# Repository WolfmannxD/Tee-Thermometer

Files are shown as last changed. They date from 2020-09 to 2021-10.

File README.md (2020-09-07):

# Tee-Thermometer

This is a small arduino project which helps to track the temperature of a hot drink. It is based on an Arduino Nano and a DS1020 digital temperature sensor. This sensor can be connected directly to the Arduino without any additional circuitry. As output, I use a 128x64 OLED Display with I2C interface. 
The temperature is logged and used to extrapolate the time when the desired temperature is reached. This is accomplished by doing a linear regression on the logarithm of the temperatures, to simplify the computation. For more information on the calculations see Tee-Thermometer.pdf. 

The main function of this device is the calculation and display of the remaining time until the tea (or other hot drink) has cooled enough to be drinkable. It also shows the remaining time until the drink is too cold. The temperature values may vary from person to person and must be changed in the sketch directly.

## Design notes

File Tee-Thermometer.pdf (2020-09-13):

## Tee-Thermometer

Zielsetzung:

Jeder kennt das Problem: Direkt nach dem Aufbrühen ist der Tee zu heiß zum Trinken, also lässt man ihn auskühlen. Dabei verliert man ihn jedoch schnell aus den Augen, und denkt erst an ihn, wenn er bereits zu kalt ist. Um diesem Problem entgegenzuwirken habe ich mir folgendes Hilfsmittel ausgedacht: Ein Gerät, welches die Temperatur des Tees misst, und die verbleibende Wartezeit berechnet bis eine gewünschte Temperatur erreicht ist. So hat man die verbleibende Zeit immer im Blick, und muss nicht immer die Temperatur erfühlen. Außerdem lässt sich leicht ein Alarm implementieren, falls gewünscht.

Theorie / Funktionsweise:

Es gibt verschiedene Herangehensweisen, um dieses Problem zu lösen. Am einfachsten ist es, den Temperaturverlauf eines typischen Tees zu messen, und daraus die benötigte Zeit zum Abkühlen abzuleiten. Bei der gleichen Anfangstemperatur, Umgebungstemperatur und Tasse dauert es immer gleich lang, bis der Tee die gewünschte Temperatur erreicht hat. Dies könnte man als open-loop Vorgehensweise bezeichnen.

Eine aufwändigere Methode ist es, die Temperatur in regelmäßigen Abständen zu messen, und daraus den Zeitpunkt für das Erreichen einer gewünschten Temperatur zu extrapolieren. Damit ist die Vorhersage nicht von eingegebenen Parametern wie der Umgebungstemperatur oder der Tasse abhängig. Außerdem wird dadurch die veränderte Abkühlzeit durch eine Verringerung der Flüssigkeitsmenge und dem Durchmischen der Flüssigkeit berücksichtigt.

Implementierung:

Da komplexe Berechnungen vorgenommen werden müssen, ist die Verwendung eines Microcontrollers unerlässlich. Hier wurde der Arduino Nano verwendet. Im Nachhinein betrachtet, wäre ein leistungsfähigerer Chip besser geeignet, aber für die Funktion reicht der Nano aus. Als Temperatursensor wurde der DS18B20 verwendet. Dies ist ein digitaler Temperatursensor, welcher mit nur einem Pin verbunden werden muss, und die Temperatur bereits digital übermittelt. Dadurch sind keine weiteren Bauteile notwendig, um die Temperatur auszulesen. Ein weiterer Vorteil ist die hohe Genauigkeit der Temperaturmessung, welche mit +- 0.2 °C angegeben wird.

Als Berechnungsgrundlage für das Auskühlen einer Flüssigkeit gilt eine Exponentialfunktion mit Offset.

T(t) = T0 e

−k t + TU

Wobei T0 die Anfangstemperatur, k die Abkühlrate und TU die Umgebungstemperatur darstellen. Da die Umgebungstemperatur, sowie die Anfangstemperatur nicht aus den Messwerten ersichtlich sind müssen sie als freie Parameter in der Modellfunktion berücksichtigt werden.

Um einen Fit der Temperaturmesswerte an diese Exponentialfunktion durchzuführen, wende ich einen Trick an. Vernachlässigen wir zunächst die Umgebungstemperatur. Angenommen sie ist bekannt, kann sie von den Messwerten subtrahiert werden. Dies vereinfacht die Formel. Jetzt kann man durch logarithmieren der Gleichung einen linearen Zusammenhang zwischen dem Logarithmus der Messwerte und der Abkühlkonstanten k erhalten. Hiermit ist es möglich eine lineare Regression durchzuführen, was sehr wenig Rechenaufwand im Vergleich zu einer nichtlinearen Optimierung erfordert. Da der Arduino Nano geringe Ressourcen aufweist, ist dies hier notwendig. Die Gleichung für den Temperaturverlauf kann wie folgt umgeschrieben werden:

l⏟n ( T − T U )

y

= −⏟k

a

⏟t

x

+ ln(T0 ⏟ )

b

Dies hat die Form einer linearen Gleichung. Die Parameter a und b können mittels einer linearen Regression bestimmt werden.

b =

∑(xi − x̅)yi
∑(xi − x̅)

2

a = y̅ − bx̅

Dabei sind x̅und y̅ die Mittelwerte von x und y.

Damit können die Parameter T0 und k bestimmt werden, was die Berechnung des Zeitpunkts des Erreichens der Trinktemperatur ermöglicht.

T0 = e

b

k = −a

Da die Umgebungstemperatur nicht bestimmt werden kann, muss die vorhergehende Berechnung für mehrere Werte für TU erfolgen, und daraus per brute-force Optimierung der am besten passende Wert bestimmt werden.

Fertigstellung:

Um das Gerät bequem nutzen zu können, wurde ein 64x32 OLED Display zur Anzeige der Temperatur und verbleibenden Zeit eingesetzt. Zusätzlich wird die verbleibende Zeit bis der Tee zu kalt ist angezeigt, damit man ihn nicht zu lange stehen lässt. Um einen mobilen Einsatz zu gewährleisten wurde ein Lithium-Ionen-Akku zusammen mit einem Lade- und Schutzschaltung basierend auf dem TP4056 Chip sowie ein Boost-Converter verwendet. Dies ermöglicht ein Laden des Akkus über micro USB. Anschließend habe ich ein passendes Gehäuse entworfen und mit einem 3D-Drucker hergestellt.

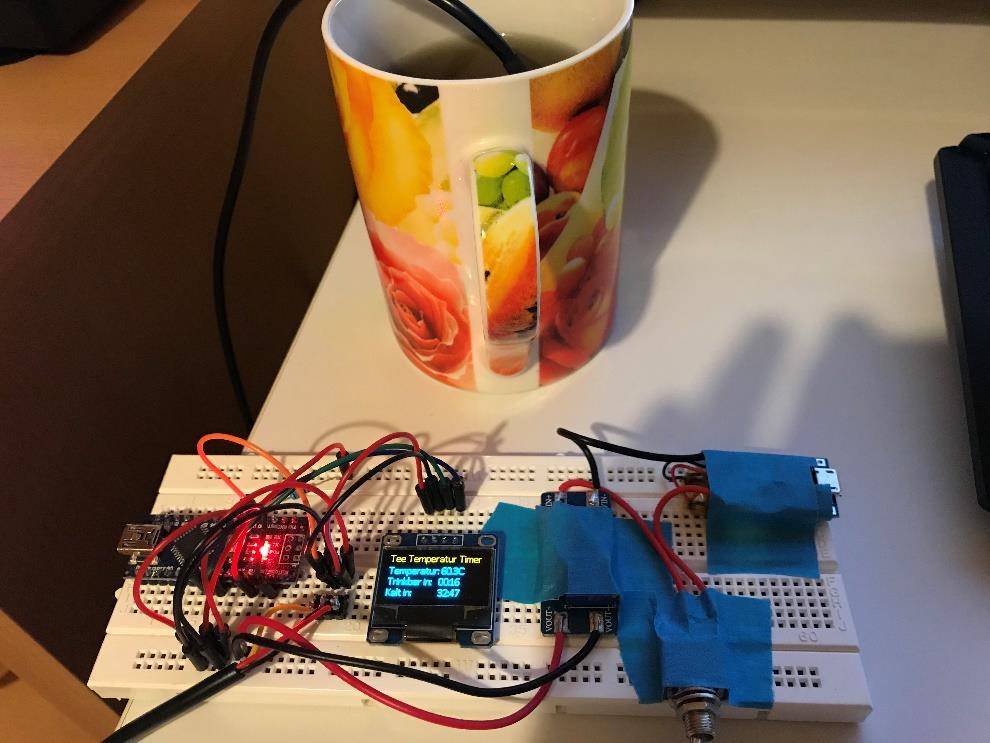
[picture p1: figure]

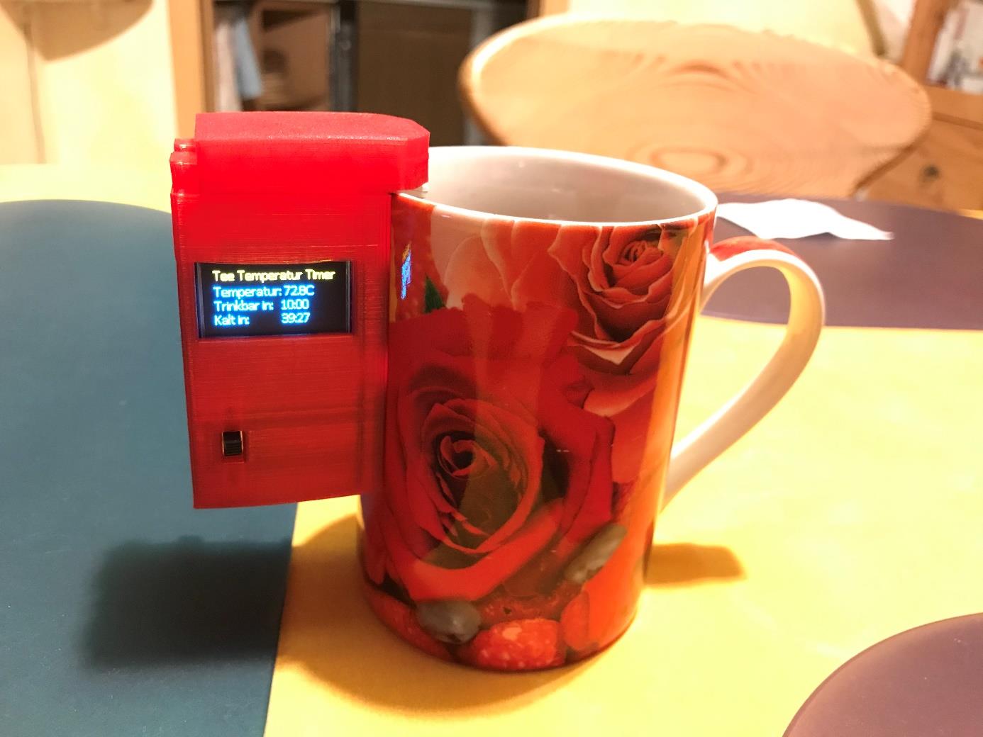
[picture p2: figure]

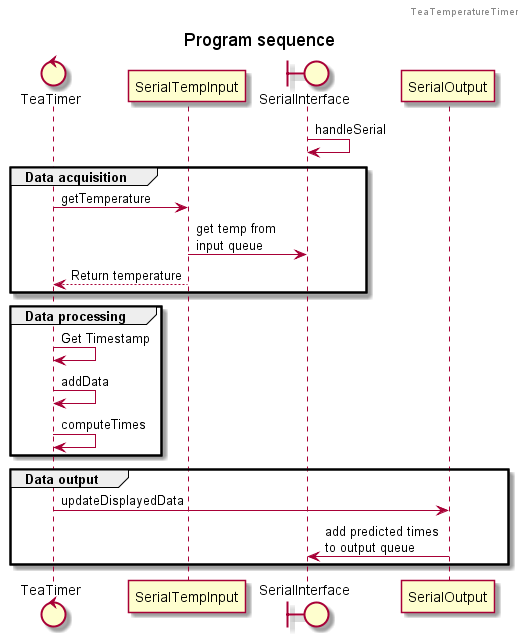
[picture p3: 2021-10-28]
Modelling/out/TeeTempearturTimer/Sequence.png

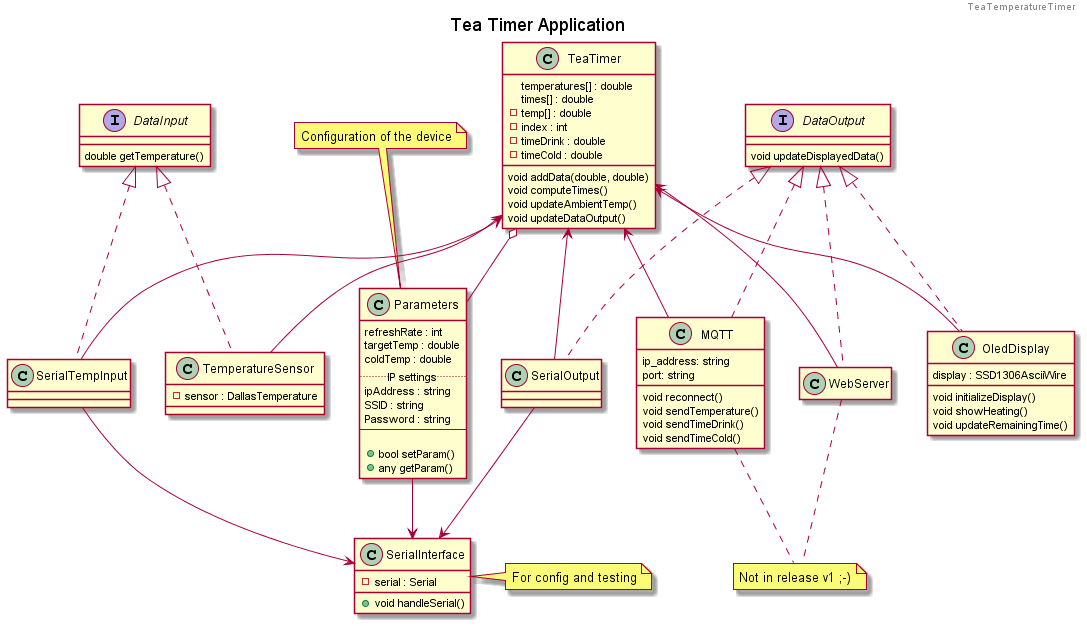
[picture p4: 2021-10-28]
Modelling/out/TeeTempearturTimer/Tea Timer Application.png

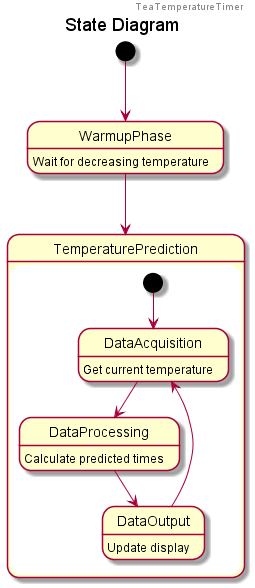
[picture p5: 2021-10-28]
Modelling/out/TeeTempearturTimer/State.png

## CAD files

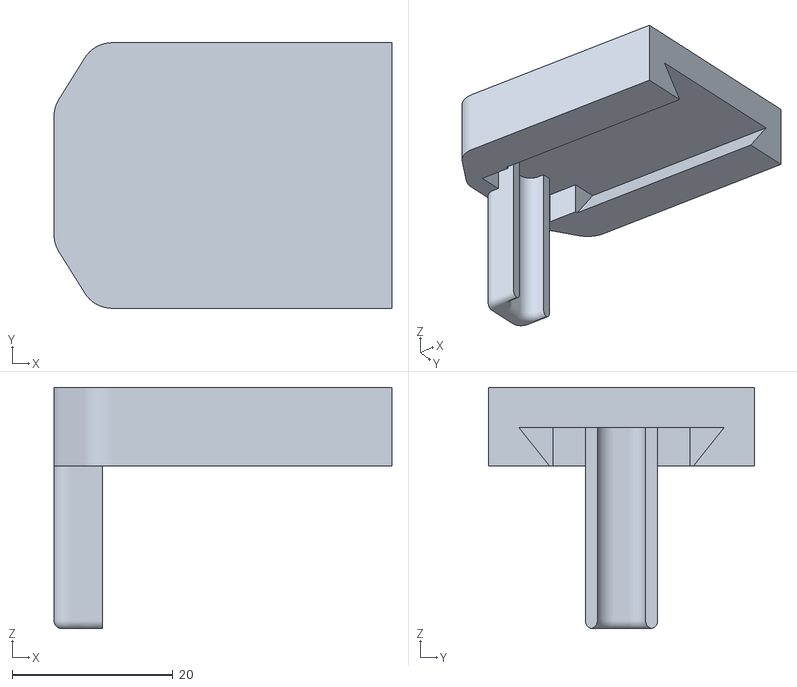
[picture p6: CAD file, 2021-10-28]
STL/Slider V4.stl
42.0 x 33.0 x 30.0

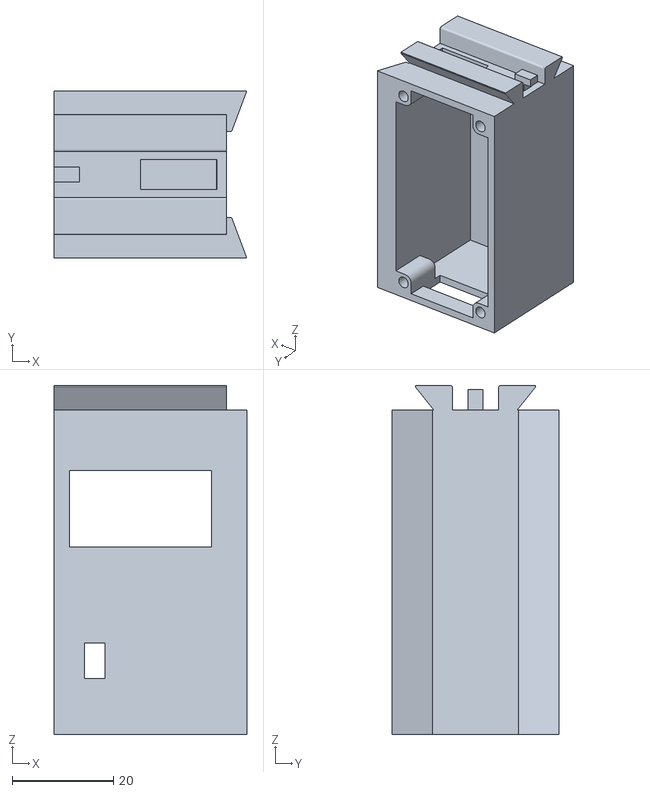
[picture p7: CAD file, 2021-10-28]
STL/Hauptteil V4.stl
38.0 x 33.0 x 68.8

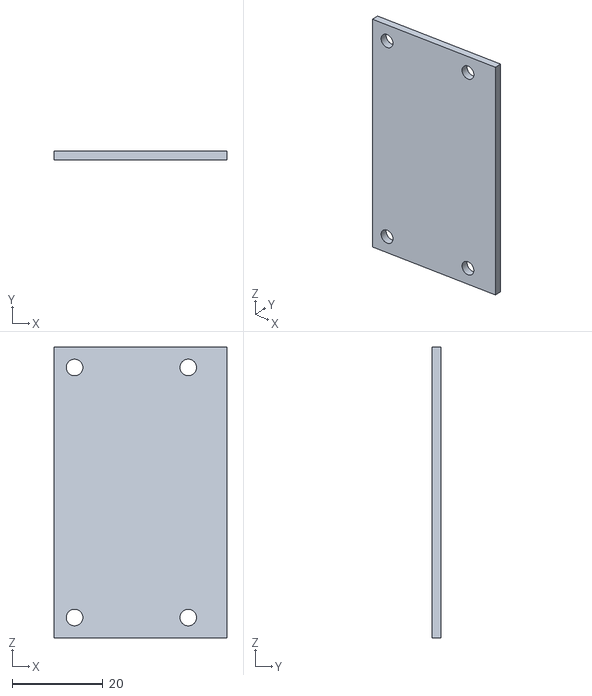
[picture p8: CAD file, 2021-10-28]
STL/Deckel V4.stl
38.0 x 2.00 x 64.0

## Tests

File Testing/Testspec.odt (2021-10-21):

Testspecification for the TeaTimer Application

# Parameter configuration

### Read parameters via serial interface

Requirement: Verify that parameters can be read via the serial interface.

Test setup: Configure the device for simulated temperature input via serial connection.

Send temperature data that puts the device out of pre-heat mode.

Check that the device is in measurement mode.

Test steps: 1. Send the string “Get Param $Param” via serial connection.

2. Wait for the answer of the device with a timeout of 200 ms.

3. Check that the answer is of the expected data type $dType.

Test parameters:

This test needs to be done for all readable parameters.

Parameter name | $Param | $dType
Refresh rate | refreshRate | Int
Target temperature | targetTemp | Double
Cold temperature | coldTemp | Double
WLAN SSID | SSID | String

### Write parameters via serial interface with valid values

Requirement: Verify that parameters can be written via the serial interface when the written value is of the correct data type and in the allowed range.

Test setup: Configure the device for simulated temperature input via serial connection.

Send temperature data that puts the device out of pre-heat mode.

Check that the device is in measurement mode.

Test steps: 1. Send the string “Set Param $Param $Value” via serial connection.

2. Wait for the answer of the device with a timeout of 200 ms.

3. Check that the answer of the device is “OK”.

4. Send the string “Get Param $Param” via serial connection.

5. Wait for the answer of the device with a timeout of 200 ms.

6. Check that the answer is $Value.

Test parameters:

This test needs to be done for all writable parameters.

Parameter name | $Param | $Value
Refresh rate | refreshRate | 5 [seconds]
Target temperature | targetTemp | 77.5 [degree Celsius]
Cold temperature | coldTemp | -1.0 [degree Celsius]
WLAN SSID | SSID | My Home Network

### Write parameters via serial interface with invalid values

Requirement: Verify that writing a parameter with an invalid value does not change the parameter. The device should not crash.

Test setup: Configure the device for simulated temperature input via serial connection. Send temperature data that puts the device out of pre-heat mode. Check that the device is in measurement mode.

Test steps: 1. Send the string “Set Param $Param $Value” via serial connection. 2. Wait for the answer of the device with a timeout of 200 ms. 3. Check that the answer of the device is “ERROR”. 4. Send the string “Get Param $Param” via serial connection. 5. Wait for the answer of the device with a timeout of 200 ms. 6. Check that the answer is not $Value.

### Write parameters and check reaction of the output

Requirement: Verify that written parameters are reloaded in the system by observing a change in the output.

Test setup: Configure the device for simulated temperature input via serial connection. Send temperature data that puts the device out of pre-heat mode. Check that the device is in measurement mode. Start sending simulated temperature data over serial connection.

Test steps: 1. Set the parameter ‘targetTemp’ to 60 °C over serial connection. 2. Wait until enough data points for time computation have been sent. 3. Get the parameter ‘timeDrink’ via serial connection as $Time_1. 4. Set the parameter ‘targetTemp’ to 40 °C over serial connection. 5. Get the parameter ‘timeDrink’ via serial connection as $Time_2. 6. Check that $Time_2 > $Time_1.

# Data processing

TBD

# Performance tests

### Test prediction accuracy with perfect data

Requirement: Verify that the extrapolated temperatures are correct within a tolerance of 5% when perfect test data is used. The time predictions shall be checked in regular intervals.

Test setup: Configure the device for simulated temperature input via serial connection.

Check that the device is in pre-heat mode.

Start sending simulated temperature data over serial connection.

Test steps: 1. Check that the device is in measurement mode when the temperature reaches 75 °C. 2. Get the parameter ‘timeDrink’ and compare it with the expected value every 5 °C until 30 °C is reached. Check that the value has a maximum deviation of 5%.

### Test prediction accuracy with data with artifacts in it

Requirement: Verify that the predicted times do not deviate more than 20% when a peak in the temperature data occurs.

### Test prediction accuracy with data with a changing slope

Requirement: Verify that the predicted time adapts in a reasonable way when the slope of the temperature curve is changing. Unrealistic results shall be rejected until the prediction has stabilized.

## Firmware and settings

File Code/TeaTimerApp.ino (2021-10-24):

#include <Arduino.h>
#include <OneWire.h>
#include <DallasTemperature.h>
#include <math.h>
#include <Wire.h>
#include "SSD1306Ascii.h"
#include "SSD1306AsciiWire.h"
#include <iostream>
#include <string>
// #include <ESP8266WiFi.h>  // macht immer noch Probleme ...
// #include <PubSubClient.h>

#include "include/TeaTimer.h"  // WTF es darf nicht im selben Verzeichnis sein???

// State of the system
bool SERIAL_ACTIVE{false};
SerialTempInput dataInput;
SerialInterface *serial;

// the setup function is run once after startup
void setup() {
    serial = new SerialInterface(); // Serial.begin etc. inside constructor
    dataInput = SerialTempInput(serial);
}

// the loop function is looped indefinitely after setup
void loop() {
    static double T;
    serial->handleSerial();
    T = dataInput.getTemperature();
    delay(2000);
    serial->write_str(String(T));
}

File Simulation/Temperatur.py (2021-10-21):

import os
import serial
import matplotlib.pyplot as plt
#import io
import time
import numpy as np
from scipy.optimize import curve_fit
import re
#import threading


def fit_func(x, a, k, c, d):
    return a*np.exp(-(x-d)*k) + c


def fit_func_ambient(x, a, k):
    return a*np.exp(-(x)*k) + T_ambient


def lin_fit(time, temperatures):
    """Use with fit_func_ambient"""
    x = time
    y = np.log(temperatures - T_ambient)
#    n = len(time)
    x_average = np.average(x)
    y_average = np.average(y)
#    b = (np.sum(x*y) - n*x_average*y_average)/(np.sum(x**2) - n*x_average**2)
    b = np.sum((x - x_average)*y)/np.sum((x - x_average)**2)
    a = y_average - b*x_average
    
    # convert
    A = np.exp(a)
    k = -b
    
    return A, k


def expofit(time, temperatures):
    xinit = 7.85, 1e-2, 20, 40
    bounds = ([0,0,0,0], [np.inf, np.inf, np.inf, np.inf])
    time = np.array(time)
    temperatures = np.array(temperatures)
    popt = curve_fit(fit_func, time, temperatures, p0=xinit, bounds=bounds)
    
    return popt


def expofit_ambient(time, temperatures):
    xinit = 7.85, 1e-2
    bounds = ([0,0], [np.inf, np.inf])
    time = np.array(time)
    temperatures = np.array(temperatures)
    popt = curve_fit(fit_func_ambient, time, temperatures, p0=xinit, bounds=bounds)
    
    return popt


def linfit(time, temperatures):
    time = np.array(time)
    temperatures = np.array(temperatures)
    popt = lin_fit(time, temperatures)
    
    return popt


def plot_data(t, T, times, data, T_trink):
    """Create the plot"""
    try:
#        print('fit')
        # popt, pcov = expofit(times, data)
#        popt2, pcov2 = expofit_ambient(times, data)
        popt3 = linfit(times, data)
        # print(popt)       
#        a, k, c, d = popt
        a, k = popt3
#        print(popt3)
#        if c < T_trink:
#            time_trink = d - np.log((T_trink - c)/a)/k
        time_trink = np.log(a/(T_trink - T_ambient))/k
        wait_time = (time_trink - times[-1])/60 # in minutes
        if wait_time < 60: # less than an hour
            if wait_time < 1:
                mesg = 'Trinkbar in {:} Sekunden'.format(int(wait_time*60))
            else:
                mesg = 'Trinkbar in {:} Minuten'.format(int(wait_time))
#            print("plot")
#            x = np.linspace(times[0], times[-1]+60, 100) # + one minute
            x = np.linspace(t[0], t[-1], 100)
            plt.clf()
            plt.ylim(30, 95)
            plt.plot(t, T, '--', color='grey')
            plt.plot(times, data, '.')
            # plt.plot(x, fit_func(x, *list(popt)), label='Normal')
#            plt.plot(x, fit_func_ambient(x, *list(popt2)), label='Ambient')
            plt.plot(x, fit_func_ambient(x, *list(popt3)), label='Linear')
            plt.plot([t[0], t[-1]], [T_trink, T_trink], '--', color='grey')
            plt.legend(loc='upper right')
            plt.title(mesg, fontsize=14)
            plt.annotate("{}".format(data[-1]), xy=(times[-1], data[-1]), xycoords='data', xytext=(5, 2), textcoords='offset points')
        plt.xlabel("t [s]")
        plt.ylabel("T [$^{\circ}$C]")
    except Exception as e:
        print(e)
    finally:
        plt.pause(0.0001)
#        plt.ion()


def temperature_logger():
    try:
        arduino = serial.Serial("Com3", timeout=15)
        # sio = io.TextIOWrapper(io.BufferedRWPair(arduino, arduino))
    except Exception as e:
        print("Please check port")
        print(e)
    print('Begin plotting')
    data = []    
    times = []
    t_zero = time.time() # Starting time
#    delta_t = 0.5 # interval in seconds
    duration = 3*60*60 # 60 minutes
    T_trink = 60 # Target temperature
    try:
        while time.time() - t_zero < duration:
#            received = arduino.readline()
#            if re.fullmatch(r"\d{2}\.\d{2}", received) is None:
#                continue
            data.append(float(arduino.readline()))
            new_time = time.time()-t_zero
            times.append(new_time)
            plt.figure(0)
            plt.ion()
            plt.clf()
            plt.plot(times, data, '.')
            if len(times) < 4:         
                continue
            plot_data(times, data, T_trink)
    except Exception as e:        
        print(e)       
    finally:
        arduino.close()
        outfile = os.path.join(os.getcwd(), 'test_data4.npz')
        np.savez(outfile, time=times, temp=data)
       
        
def receive_state():
    try:
        arduino = serial.Serial("Com3", timeout=15)
        # sio = io.TextIOWrapper(io.BufferedRWPair(arduino, arduino))
    except Exception as e:
        print("Please check port")
        print(e)
    try:
        plt.ion()
        arraysize = 50
        T_trink = 60
        T_cold = 40
        while(True):
            received = arduino.readline()
            data = [float(rec) for rec in received.split(b',')]
            if len(data) < arraysize+4:
                continue # data not complete
            temperatures = np.array(data[:arraysize])
            times = np.array(data[arraysize:2*arraysize])
            A = data[-4]
            k = data[-3]
            time_trink = data[-2]
            time_cold = data[-1]
            plt.figure(1)
            plt.clf()
            plt.plot(times, temperatures)
            A1, k1 = lin_fit(times, temperatures)
            time_trink1 = np.log(A1/(T_trink - T_ambient))/k1
            time_cold1 = np.log(A1/(T_cold - T_ambient))/k1
            t_plot = np.linspace(0, 3000)
            wait_time = (time_trink1 - times[-1])/60 # in minutes
            if wait_time < 60: # less than an hour
                if wait_time < 1:
                    mesg = 'Trinkbar in {:} Sekunden'.format(int(wait_time*60))
                else:
                    mesg = 'Trinkbar in {:} Minuten'.format(int(wait_time))
                plt.title(mesg, fontsize=14)
            plt.plot(t_plot, fit_func_ambient(t_plot, A, k), label='Arduino')
            plt.plot(t_plot, fit_func_ambient(t_plot, A1, k1), label= 'Python')
            plt.plot([time_trink, time_trink], [30, 70], label = 'Arduino')
            plt.plot([time_trink1, time_trink1], [30, 70], label= 'Python')
            plt.plot([time_cold, time_cold], [30, 70], label = 'Arduino')
            plt.plot([time_cold1, time_cold1], [30, 70], label= 'Python')
            plt.legend(loc='best')
            plt.pause(0.001)
    finally:
        arduino.close()
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

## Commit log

2021-10-24 sending temperature over serial working
2021-10-28 add STL files to repo
    [Deckel V4.stl, Hauptteil V4.stl, Slider V4.stl]
